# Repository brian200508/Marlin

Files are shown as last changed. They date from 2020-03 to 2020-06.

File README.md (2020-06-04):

Brian Schroeder's RepRap FTI-Strap
==================================
Another Fischertechnik RepRap Strap (using Marlin 3D Printer Firmware) built with Fischertechnik parts of the late 80's and some non-Fischertechnik pars from today; especially
- Nema 17 Stepper Motors
- MK 8 Extruder
- Arduino AVR Mega ATMEGA256
- RAMPS 1.6 Board
- GT2 timing belts and gears

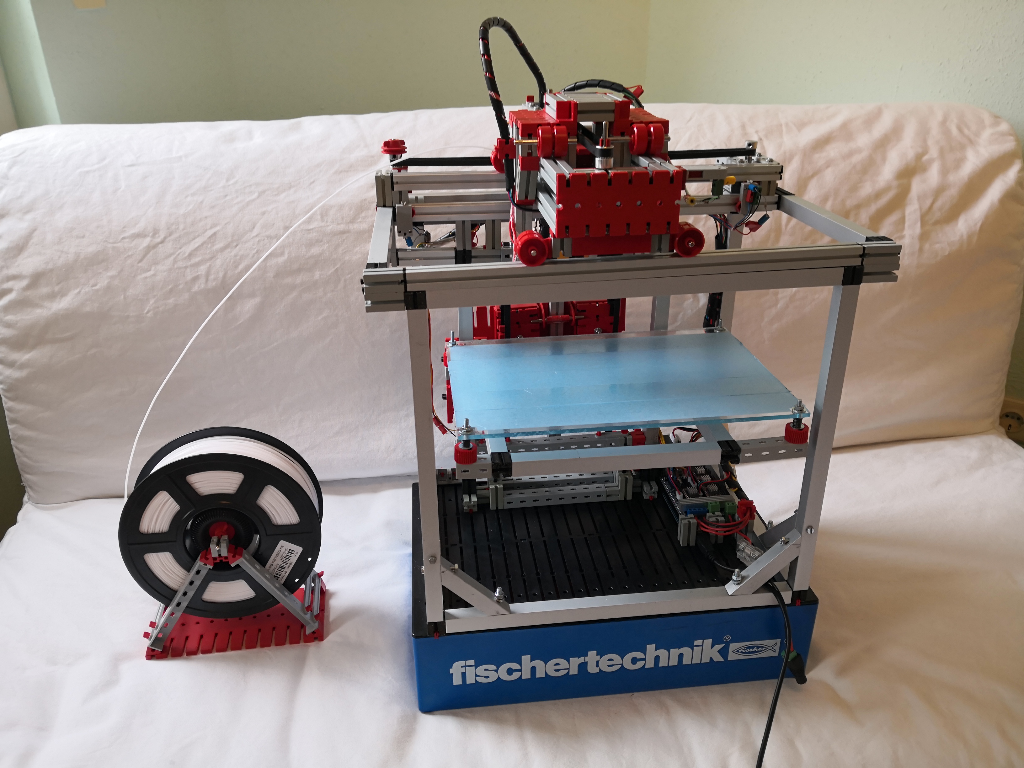
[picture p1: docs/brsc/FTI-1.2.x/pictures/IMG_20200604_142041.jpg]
Photo RepRap FTI-Strap


For more Details concerning the mechanics see ```docs/brsc/FTI-1.2.x```.

Thanks and very best Regards to Marlin and RepRap.
- https://github.com/MarlinFirmware/Marlin
- https://reprap.org

# Marlin 3D Printer Firmware








Additional documentation can be found at the [Marlin Home Page](http://marlinfw.org/).
Please let us know if Marlin misbehaves in any way. Volunteers are standing by!

## Marlin 2.0

Marlin 2.0 takes this popular RepRap firmware to the next level by adding support for much faster 32-bit and ARM-based boards while improving support for 8-bit AVR boards. Read about Marlin's decision to use a "Hardware Abstraction Layer" below.

Download earlier versions of Marlin on the [Releases page](https://github.com/MarlinFirmware/Marlin/releases).

## Building Marlin 2.0

To build Marlin 2.0 you'll need [Arduino IDE 1.8.8 or newer](https://www.arduino.cc/en/main/software) or [PlatformIO](http://docs.platformio.org/en/latest/ide.html#platformio-ide). Detailed build and install instructions are posted at:

  - [Installing Marlin (Arduino)](http://marlinfw.org/docs/basics/install_arduino.html)
  - [Installing Marlin (VSCode)](http://marlinfw.org/docs/basics/install_platformio_vscode.html).

### Supported Platforms

  Platform|MCU|Example Boards
  --------|---|-------
  [Arduino AVR](https://www.arduino.cc/)|ATmega|RAMPS, Melzi, RAMBo
  [Teensy++ 2.0](http://www.microchip.com/wwwproducts/en/AT90USB1286)|AT90USB1286|Printrboard
  [Arduino Due](https://www.arduino.cc/en/Guide/ArduinoDue)|SAM3X8E|RAMPS-FD, RADDS, RAMPS4DUE
  [LPC1768](http://www.nxp.com/products/microcontrollers-and-processors/arm-based-processors-and-mcus/lpc-cortex-m-mcus/lpc1700-cortex-m3/512kb-flash-64kb-sram-ethernet-usb-lqfp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)|ARM® Cortex-M3|MKS SBASE, Re-ARM, Selena Compact
  [LPC1769](https://www.nxp.com/products/processors-and-microcontrollers/arm-microcontrollers/general-purpose-mcus/lpc1700-cortex-m3/512kb-flash-64kb-sram-ethernet-usb-lqfp100-p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)|ARM® Cortex-M3|Smoothieboard, Azteeg X5 mini, TH3D EZBoard
  [STM32F103](https://www.st.com/en/microcontrollers-microprocessors/stm32f103.html)|ARM® Cortex-M3|Malyan M200, GTM32 Pro, MKS Robin, BTT SKR Mini
  [STM32F401](https://www.st.com/en/microcontrollers-microprocessors/stm32f401.html)|ARM® Cortex-M4|ARMED, Rumba32, SKR Pro, Lerdge, FYSETC S6
  [STM32F7x6](https://www.st.com/en/microcontrollers-microprocessors/stm32f7x6.html)|ARM® Cortex-M7|The Borg, RemRam V1
  [SAMD51P20A](https://www.adafruit.com/product/4064)|ARM® Cortex-M4|Adafruit Grand Central M4
  [Teensy 3.5](https://www.pjrc.com/store/teensy35.html)|ARM® Cortex-M4|
  [Teensy 3.6](https://www.pjrc.com/store/teensy36.html)|ARM® Cortex-M4|

## Submitting Changes

- Submit **Bug Fixes** as Pull Requests to the ([bugfix-2.0.x](https://github.com/MarlinFirmware/Marlin/tree/bugfix-2.0.x)) branch.
- Submit **New Features** to the ([dev-2.1.x](https://github.com/MarlinFirmware/Marlin/tree/dev-2.1.x)) branch.
- Follow the [Coding Standards](http://marlinfw.org/docs/development/coding_standards.html) to gain points with the maintainers.
- Please submit your questions and concerns to the [Issue Queue](https://github.com/MarlinFirmware/Marlin/issues).

## Marlin Support

For best results getting help with configuration and troubleshooting, please use the following resources:

- [Marlin Documentation](http://marlinfw.org) - Official Marlin documentation
- [Marlin Discord](https://discord.gg/n5NJ59y) - Discuss issues with Marlin users and developers
- Facebook Group ["Marlin Firmware"](https://www.facebook.com/groups/1049718498464482/)
- RepRap.org [Marlin Forum](http://forums.reprap.org/list.php?415)
- [Tom's 3D Forums](https://discuss.toms3d.org/)
- Facebook Group ["Marlin Firmware for 3D Printers"](https://www.facebook.com/groups/3Dtechtalk/)
- [Marlin Configuration](https://www.youtube.com/results?search_query=marlin+configuration) on YouTube

## Credits

The current Marlin dev team consists of:

 - Scott Lahteine [[@thinkyhead](https://github.com/thinkyhead)] - USA &nbsp; [Donate](http://www.thinkyhead.com/donate-to-marlin) / Flattr: 
 - Roxanne Neufeld [[@Roxy-3D](https://github.com/Roxy-3D)] - USA
 - Chris Pepper [[@p3p](https://github.com/p3p)] - UK
 - Bob Kuhn [[@Bob-the-Kuhn](https://github.com/Bob-the-Kuhn)] - USA
 - João Brazio [[@jbrazio](https://github.com/jbrazio)] - Portugal
 - Erik van der Zalm [[@ErikZalm](https://github.com/ErikZalm)] - Netherlands &nbsp; 

## License

Marlin is published under the [GPL license](/LICENSE) because we believe in open development. The GPL comes with both rights and obligations. Whether you use Marlin firmware as the driver for your open or closed-source product, you must keep Marlin open, and you must provide your compatible Marlin source code to end users upon request. The most straightforward way to comply with the Marlin license is to make a fork of Marlin on Github, perform your modifications, and direct users to your modified fork.

While we can't prevent the use of this code in products (3D printers, CNC, etc.) that are closed source or crippled by a patent, we would prefer that you choose another firmware or, better yet, make your own.

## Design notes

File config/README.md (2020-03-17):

# Where have all the configurations gone?

## https://github.com/MarlinFirmware/Configurations/archive/release-2.0.5.zip

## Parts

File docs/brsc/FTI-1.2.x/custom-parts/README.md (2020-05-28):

Brian Schroeder's RepRap FTI-Strap
==================================

Custom parts required for brsc/FTI-1.2.1.

# Chassis

          O. o . . . . . . . . . . . .oO
         /. .|. . . . . . . . . . . . /
        f    b  o          o         f|
       /     |  g          g        / b
      o............................o  |
      ..+----------- a ----------+.. :|
        |  e:+ .g.         g     |  e:+
        b  :/   O. . . . . O     b  :/
        |__/ _ e                 |__/ _ e
        |\c                     /| c
        |/\ d                d / |/
        L----------- a ----------R

## Self printed parts
- o) 6x 'aluminum-square-tube-15x15-to-Fischertechnik-adapter-15' aluminum-square-tube-15x15-to-Fischertechnik-adapter-15
- O) 4x 'aluminum-square-tube-15x15-to-Fischertechnik-adapter-45' aluminum-square-tube-15x15-to-Fischertechnik-adapter-45
- L) 1 part of 'aluminum-square-tube-15x15-to-Fischertechnik-adapter-x-y-z-15-L' aluminum-square-tube-15x15-to-Fischertechnik-adapter-x-y-z-15-L
- R) 1 part of 'aluminum-square-tube-15x15-to-Fischertechnik-adapter-x-y-z-15-R' aluminum-square-tube-15x15-to-Fischertechnik-adapter-x-y-z-15-R
- +) 4x 'aluminum-square-tube-15x15-to-Fischertechnik-adapter-y-z-15' aluminum-square-tube-15x15-to-Fischertechnik-adapter-y-z-15

## Standard (non-Fischertechnik parts)
- a) 2x aluminium square tube 15mm x 15mm, length=330mm
- b) 4x aluminium square tube 15mm x 15mm, length=300mm
- c) 2x aluminium square tube 15mm x 15mm, length=210mm
- d) 2x aluminium square tube 15mm x 15mm, length=85mm
- e) 4x aluminium square tube 15mm x 15mm, length=105mm
- f) 2x aluminium square tube 15mm x 15mm, length=180mm
- g) 2x aluminium square tube 15mm x 15mm, length=240mm
- 8x Screw M4, etc.
- 8x Screw M5, etc.

# Bed

Chassis only

                . . . . . . . . . . .
                :...o----- d -----o.:
                :  :               ::
                H+==------ e ------=:+
              . O. . . .  ... . . . O. . ..
               O:         .        O:
              Oo--- a --~~~~- b -oO : 
             / \: . . . .\. . . ./.\.
            c                   c
         . L-------- f --------L. . ..

Chassis with Plexiglass board (P) and angles (*)

                . . . . . . . . . . .
                :...o----- d -----o.:
              PPPPPPPPPPPPPPPPPPPPPPPPPPPPP
             PS H+==------ e ------=:+   PS
            P . O. . . .  ... . . . O. .P..
           P   O:         .        O:  P
          P   Oo--- a --~~~~- b -oO : P
         PPPPPPPPPPPPPPPPPPPPPPPPPPPPP
         S  c                   c    S
         . L-------- f --------L. . ..

## Self printed parts
- +) 2x 'aluminum-square-tube-15x15-to-Fischertechnik-adapter-x-y-30-X-X'; one shortened at junction ```o_+``` aluminum-square-tube-15x15-to-Fischertechnik-adapter-x-y-30-X-X
- o) 4x 'aluminum-square-tube-15x15-to-Fischertechnik-adapter-15' aluminum-square-tube-15x15-to-Fischertechnik-adapter-15
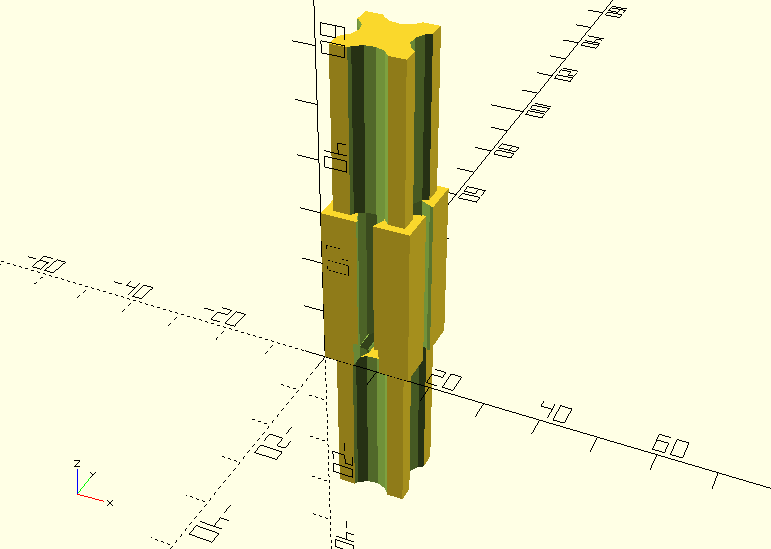
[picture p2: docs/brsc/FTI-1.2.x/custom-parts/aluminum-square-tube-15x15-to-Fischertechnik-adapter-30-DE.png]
aluminum-square-tube-15x15-to-Fischertechnik-adapter-30-DE
- ~) 1x 'aluminum-square-tube-15x15-to-Fischertechnik-adapter-30-DE' 
- O) 2x 'aluminum-square-tube-15x15-to-Fischertechnik-adapter-75' aluminum-square-tube-15x15-to-Fischertechnik-adapter-75
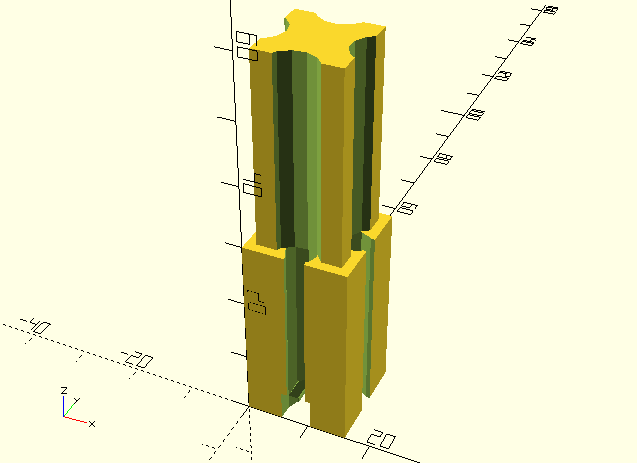
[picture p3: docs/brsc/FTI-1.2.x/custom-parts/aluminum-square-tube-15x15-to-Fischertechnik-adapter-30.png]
aluminum-square-tube-15x15-to-Fischertechnik-adapter-30
- =) 2x 'aluminum-square-tube-15x15-to-Fischertechnik-adapter-30' 
- L) 2x 'aluminum-square-tube-15x15-to-Fischertechnik-adapter-y-z-15' aluminum-square-tube-15x15-to-Fischertechnik-adapter-y-z-15

## Standard (non-Fischertechnik parts)
- a) 1x aluminium square tube 15mm x 15mm, length=75mm
- b) 1x aluminium square tube 15mm x 15mm, length=45mm
- c) 2x aluminium square tube 15mm x 15mm, length=120mm
- d) 1x aluminium square tube 15mm x 15mm, length=75mm
- e) 1x aluminium square tube 15mm x 15mm, length=105mm
- f) 1x aluminium square tube 15mm x 15mm, length=180mm
- S) 8x Screw M4, etc.
- P) 1x Plexiglass board 300mm x 210mm, d=5mm

Details see photos.

# Mechanics and Gears

## Thingiverse
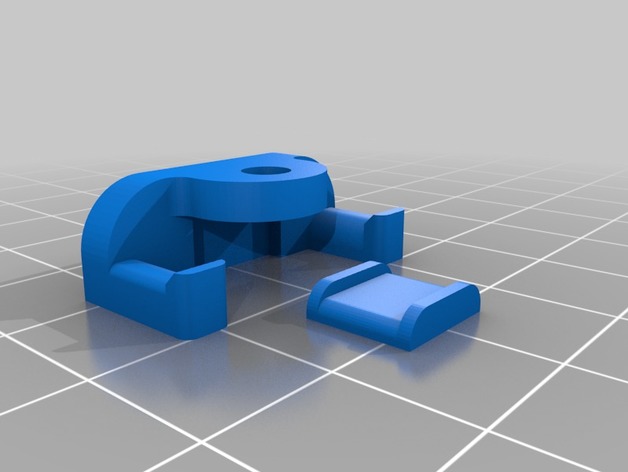
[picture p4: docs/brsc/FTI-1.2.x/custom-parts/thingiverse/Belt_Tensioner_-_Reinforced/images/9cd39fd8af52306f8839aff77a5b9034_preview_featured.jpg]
Belt_Tensioner_-_Reinforced
- 2x 'Belt_Tensioner_-_Reinforced'

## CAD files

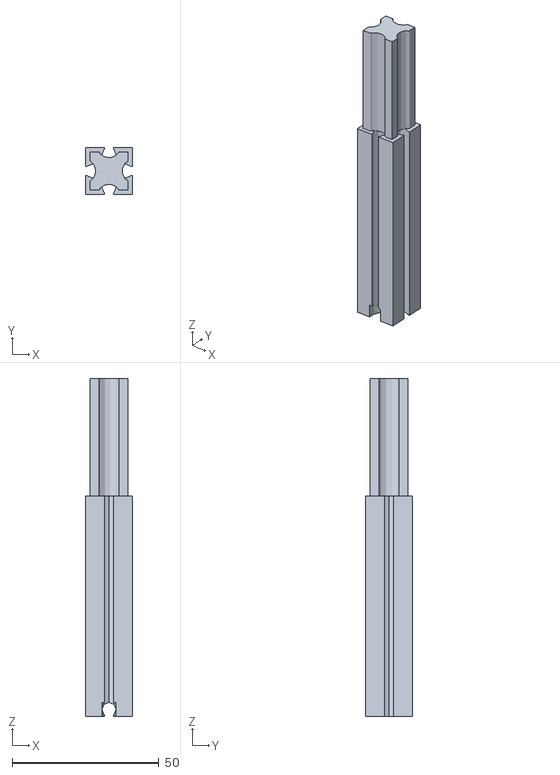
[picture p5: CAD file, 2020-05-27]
docs/brsc/FTI-1.2.x/custom-parts/aluminum-square-tube-15x15-to-Fischertechnik-adapter-75.stl
16.0 x 16.0 x 115.0

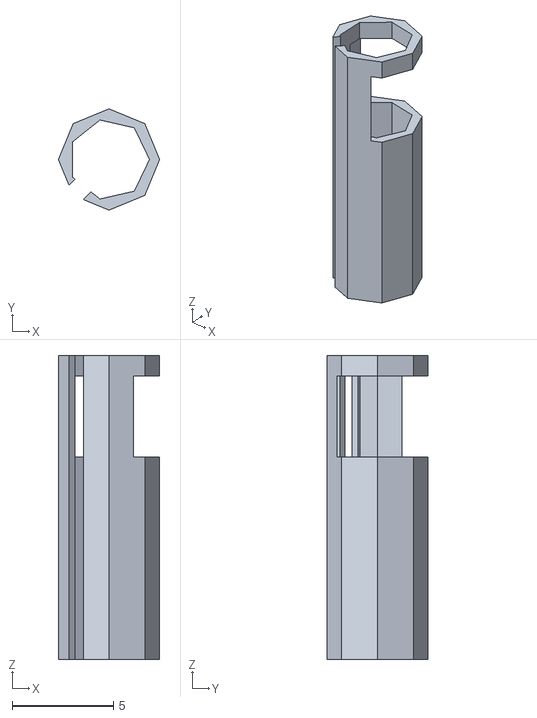
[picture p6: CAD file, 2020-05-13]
docs/brsc/FTI-1.2.x/custom-parts/not-used/axis-5mm-to-4mm-Fischertechnik-adapter.stl
5.00 x 5.00 x 15.0

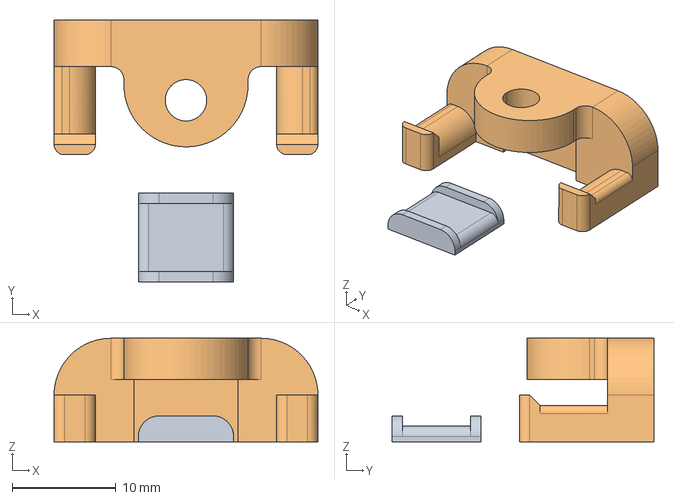
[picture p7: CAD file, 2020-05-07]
docs/brsc/FTI-1.2.x/custom-parts/thingiverse/Belt_Tensioner_-_Reinforced/files/Belt_Tensioner_-_Thicker.stp
25.5 x 25.3 x 10.0 mm

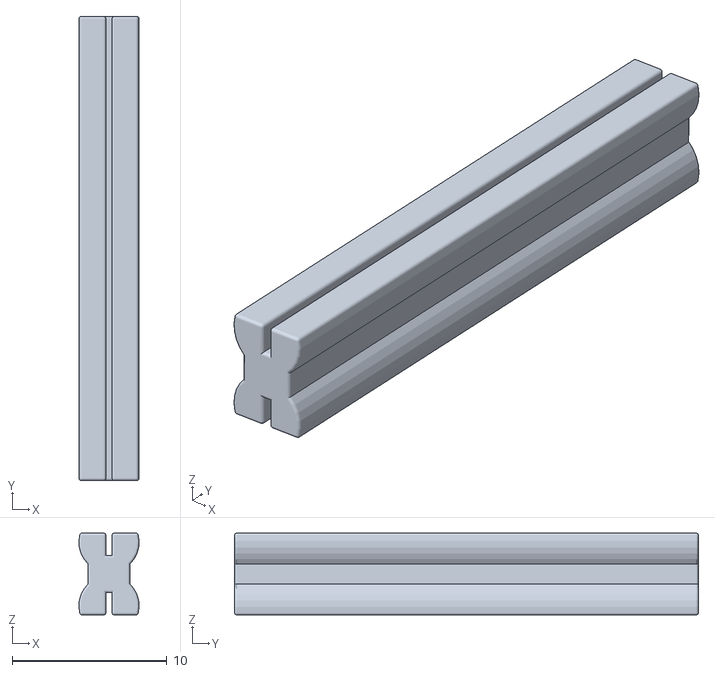
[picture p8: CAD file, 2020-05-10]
docs/brsc/FTI-1.2.x/custom-parts/thingiverse/fischertechnik_double_flat_connector/files/Connector_30mm_v1.stl
3.90 x 30.0 x 5.30

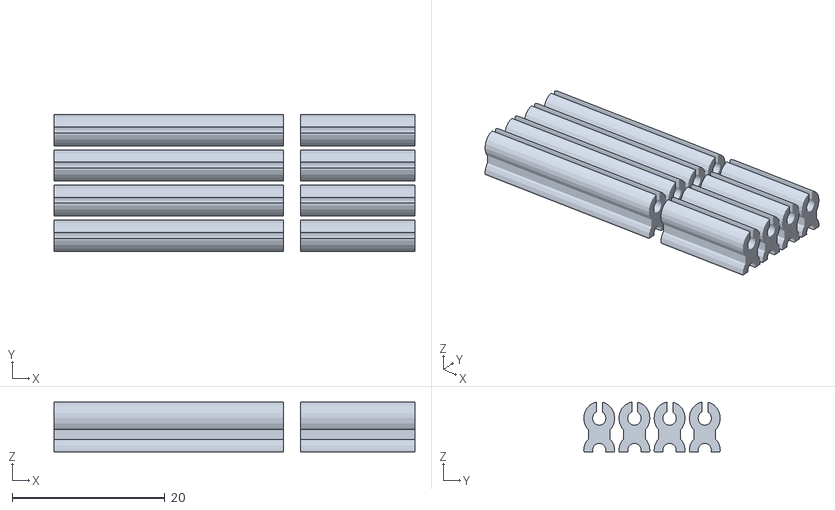
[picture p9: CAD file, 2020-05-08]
docs/brsc/FTI-1.2.x/custom-parts/thingiverse/Fischertechnik_Double_GroovePin_SmartLab/files/fischertechnik_double_groovepin_smartlab.stl
47.2 x 17.9 x 6.50

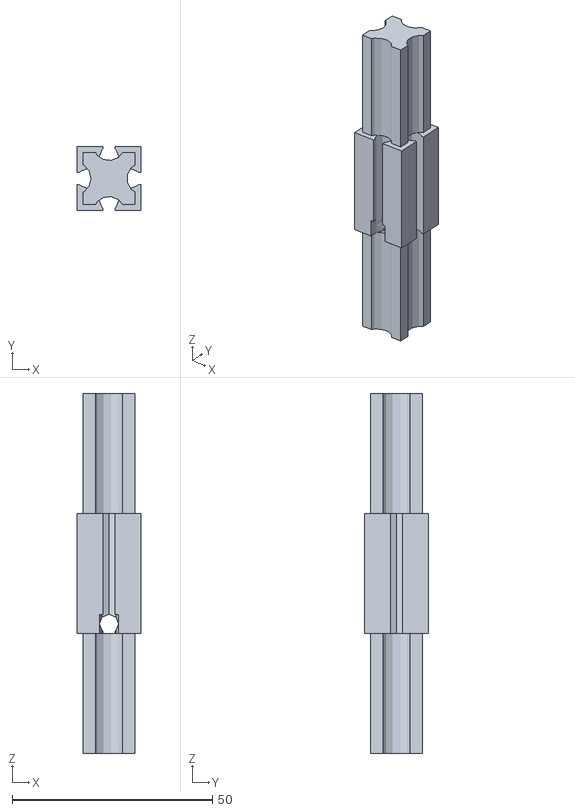
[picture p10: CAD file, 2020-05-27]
docs/brsc/FTI-1.2.x/custom-parts/aluminum-square-tube-15x15-to-Fischertechnik-adapter-30-DE.stl
16.0 x 16.0 x 90.0

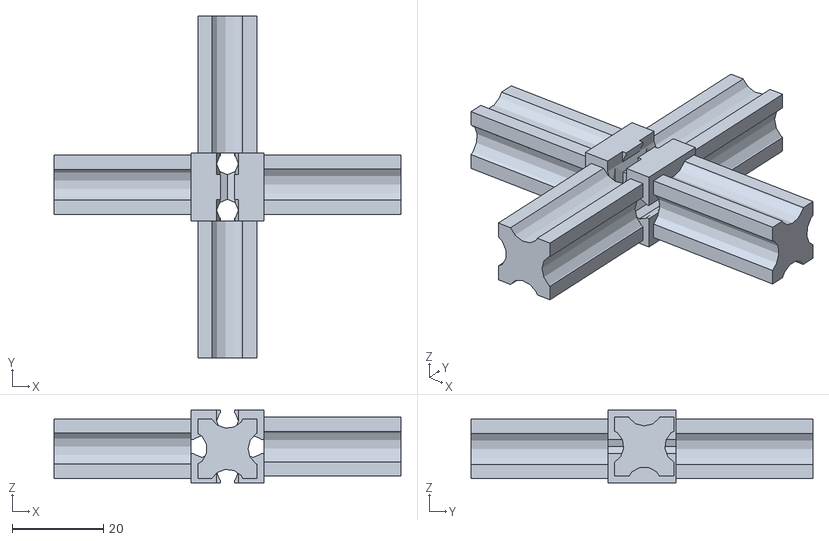
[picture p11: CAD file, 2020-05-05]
docs/brsc/FTI-1.2.x/custom-parts/not-used/aluminum-square-tube-15x15-to-Fischertechnik-adapter-x-y-15-X-Z.stl
76.0 x 75.0 x 16.0

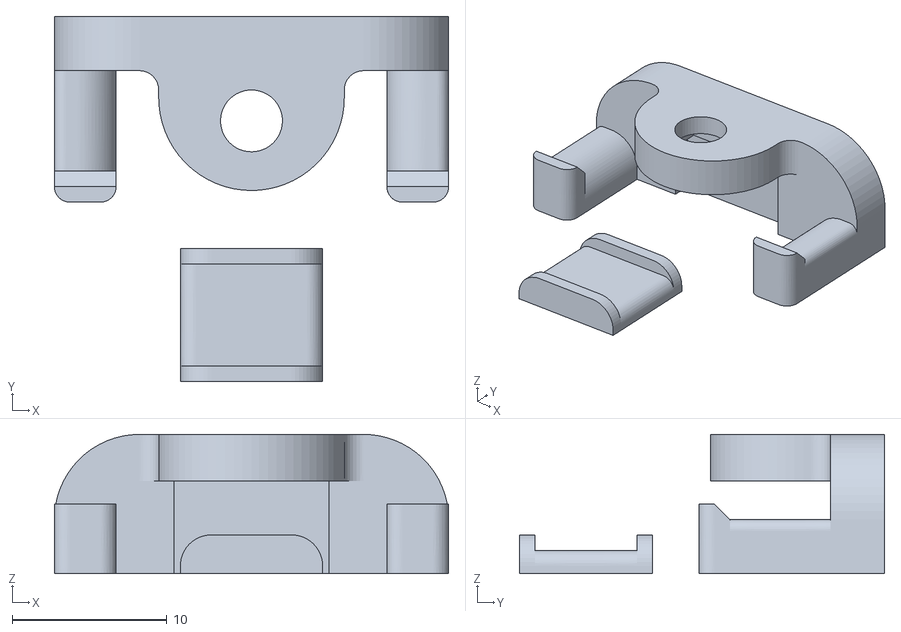
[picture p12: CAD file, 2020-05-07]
docs/brsc/FTI-1.2.x/custom-parts/thingiverse/Belt_Tensioner_-_Reinforced/files/Belt_Tensioner.stl
25.5 x 23.6 x 9.00

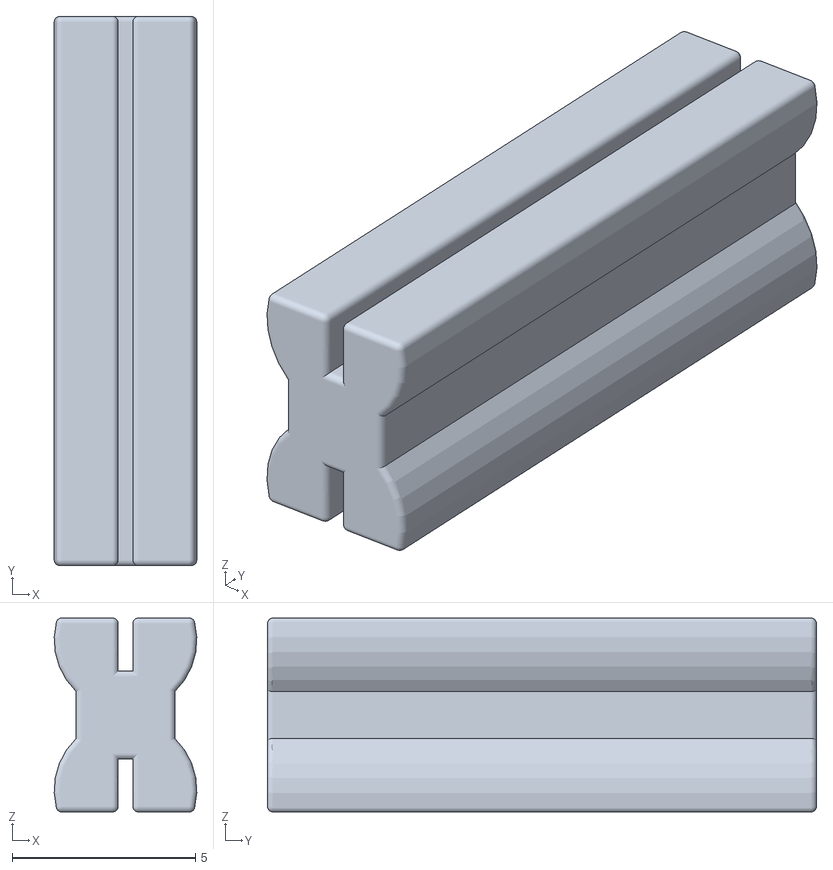
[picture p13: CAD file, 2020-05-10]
docs/brsc/FTI-1.2.x/custom-parts/thingiverse/fischertechnik_double_flat_connector/files/Connector_15mm_v1.stl
3.90 x 15.0 x 5.30

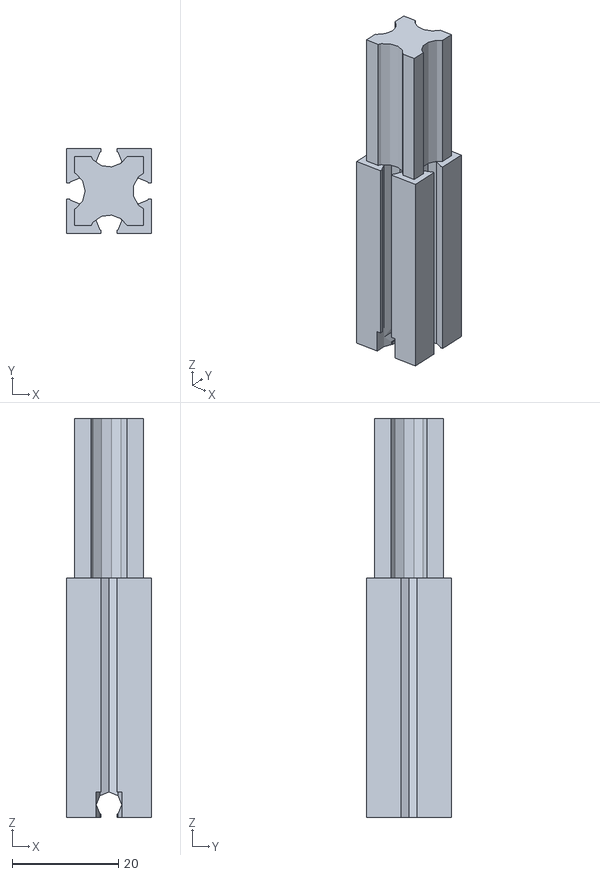
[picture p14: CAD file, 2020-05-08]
docs/brsc/FTI-1.2.x/custom-parts/aluminum-square-tube-15x15-to-Fischertechnik-adapter-45.stl
16.0 x 16.0 x 75.0

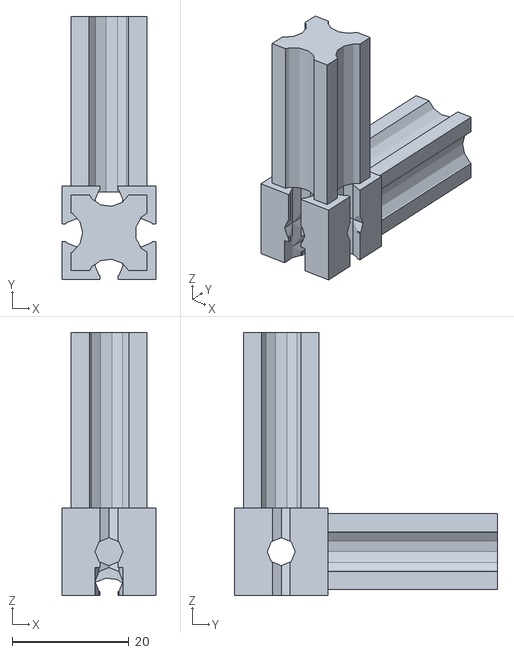
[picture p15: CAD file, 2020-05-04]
docs/brsc/FTI-1.2.x/custom-parts/not-used/aluminum-square-tube-15x15-to-Fischertechnik-adapter-y-z-15-with-hole.stl
16.0 x 45.0 x 45.0

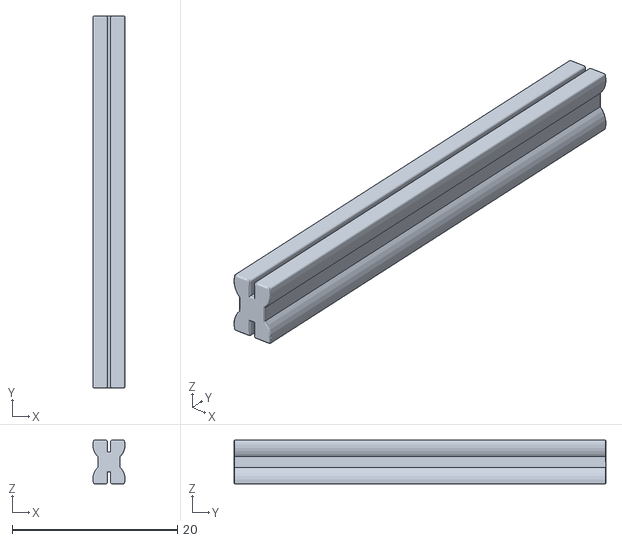
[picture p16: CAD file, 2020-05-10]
docs/brsc/FTI-1.2.x/custom-parts/thingiverse/fischertechnik_double_flat_connector/files/Connector_45mm_v1.stl
3.90 x 45.0 x 5.30

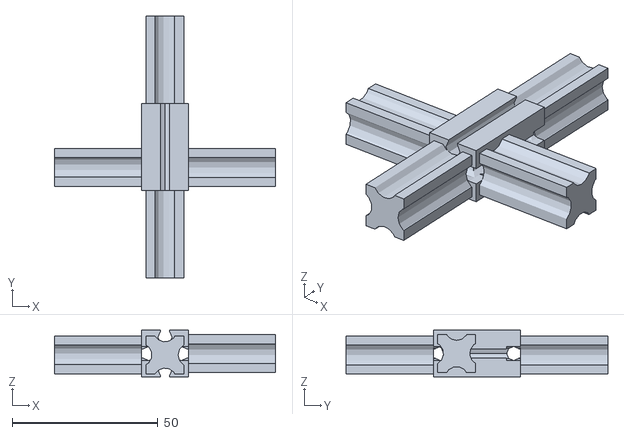
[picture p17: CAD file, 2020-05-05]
docs/brsc/FTI-1.2.x/custom-parts/aluminum-square-tube-15x15-to-Fischertechnik-adapter-x-y-30-X-X.stl
76.0 x 90.0 x 16.0

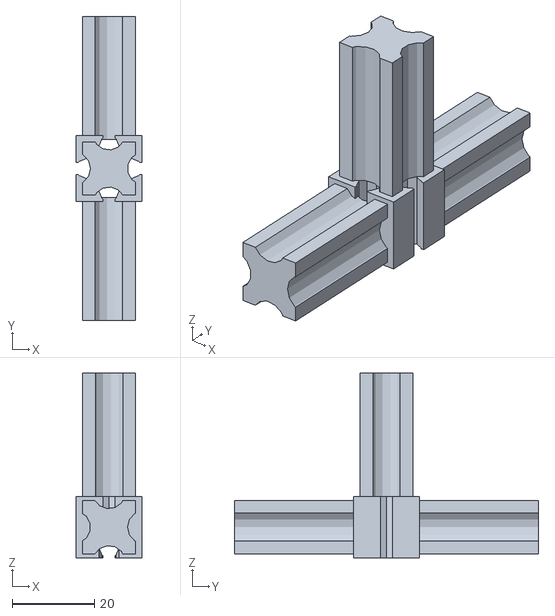
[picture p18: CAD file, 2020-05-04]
docs/brsc/FTI-1.2.x/custom-parts/not-used/aluminum-square-tube-15x15-to-Fischertechnik-adapter-y-z-15-T.stl
16.0 x 74.0 x 45.0

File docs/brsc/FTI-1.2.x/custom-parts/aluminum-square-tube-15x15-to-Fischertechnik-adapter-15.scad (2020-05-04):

/**
 * Create an adapter for connecting a 15x15 square tube to Fischertechnik.
 *
 * @author Brian Schroeder
 * @since 21.04.2020
 */

/* [End Cap length] */
// Fischertechnik compatible end cap length in millimeters
EndCapLength=15; // [15, 30, 45, 60, 75, 90]

/*
 * Create the adapter with Fischertechnik compatible end cap length passed by the argument.
 *
 * @param ftiEndCapLength end cap length in millimeters (default is 15)
 */
module ftiSpuareTubeAdapter15x15(ftiEndCapLength=15) {

    union() {
        dBlock=15 + 1; // block (max) diameter + some more around (adjust to Your printer)
        hTubeConn=(ftiEndCapLength < 60) ? 30 : (ftiEndCapLength < 75 ? 45 : 60);
        dCarveOut=8; // carve out diameter
        oCarveOut=6; // carve out offset
        dConnector=12.5 + .5; // connector (max) diameter + some more around (adjust to Your printer)
        dBorder=(dBlock-dConnector)/2; // the square tube border diameter

        // Fischertechnik connector part
        difference() {
            dFti=4 + .8; // axis diameter 4mm + some space around
            gFtiW=3; // with of gap
            gFtiD=2; // depth of gap
            cube([dBlock, dBlock, ftiEndCapLength]);
            // axis
            translate([dBlock/2,dFti/2,0])cylinder(h=ftiEndCapLength, d=dFti);
            translate([dBlock/2,dBlock-dFti/2,0])cylinder(h=ftiEndCapLength, d=dFti);
            translate([dBlock-dFti/2,dBlock/2,0])cylinder(h=ftiEndCapLength, d=dFti);
            translate([dFti/2,dBlock/2,0])cylinder(h=ftiEndCapLength, d=dFti);
            // space
            translate([dBlock/2-gFtiW/2,0,0])cube([gFtiW, gFtiD, ftiEndCapLength]);
            translate([dBlock/2-gFtiW/2,dBlock-gFtiD,0])cube([gFtiW, gFtiD, ftiEndCapLength]);
            translate([dBlock-gFtiW/2,dBlock/2-gFtiW/2,0])cube([gFtiD, gFtiW, ftiEndCapLength]);
            translate([0,dBlock/2-gFtiW/2,0])cube([gFtiD, gFtiW, ftiEndCapLength]);
            // orthoganal axis at end
            translate([dBlock/2, dBlock, dFti/2])rotate([90, 0, 0])cylinder(h=dBlock, d=dFti);
            translate([dBlock/2-dFti/2, dBlock-dFti/2, 0])cube([dFti, dFti, dFti]);
            translate([dBlock/2-dFti/2, 0-dFti/2, 0])cube([dFti, dFti, dFti]);
            translate([dBlock/2+gFtiW/2, 0, -gFtiD/2])rotate([270, 180, 0])cube([gFtiW, gFtiD, dBlock]);
        }

        // square tube connector part
        translate([dBorder, dBorder, ftiEndCapLength])difference() {
            // corpus
            cube([dConnector, dConnector, hTubeConn]);
            // space
            translate([dConnector/2,dCarveOut/2-oCarveOut,0])cylinder(h=hTubeConn, d=dCarveOut);
            translate([dConnector/2,dConnector-dCarveOut/2+oCarveOut,0])cylinder(h=hTubeConn, d=dCarveOut);
            translate([dConnector-dCarveOut/2+oCarveOut,dConnector/2,0])cylinder(h=hTubeConn, d=dCarveOut);
            translate([dCarveOut/2-oCarveOut,dConnector/2,0])cylinder(h=hTubeConn, d=dCarveOut);
        }
    }
}

ftiSpuareTubeAdapter15x15(EndCapLength);

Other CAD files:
docs/brsc/FTI-1.2.x/custom-parts/aluminum-square-tube-15x15-to-Fischertechnik-adapter-15.stl
docs/brsc/FTI-1.2.x/custom-parts/not-used/aluminum-square-tube-15x15-to-Fischertechnik-adapter-30.stl
docs/brsc/FTI-1.2.x/custom-parts/aluminum-square-tube-15x15-to-Fischertechnik-adapter-x-y-z-15-R.stl
docs/brsc/FTI-1.2.x/custom-parts/not-used/Fischertechnik-compatible-building-block-with-hole-90.stl
docs/brsc/FTI-1.2.x/custom-parts/aluminum-square-tube-15x15-to-Fischertechnik-adapter-30-DE.scad
docs/brsc/FTI-1.2.x/custom-parts/aluminum-square-tube-15x15-to-Fischertechnik-adapter-30.scad
docs/brsc/FTI-1.2.x/custom-parts/aluminum-square-tube-15x15-to-Fischertechnik-adapter-45.scad
docs/brsc/FTI-1.2.x/custom-parts/aluminum-square-tube-15x15-to-Fischertechnik-adapter-30.stl
docs/brsc/FTI-1.2.x/custom-parts/aluminum-square-tube-15x15-to-Fischertechnik-adapter-75.scad
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

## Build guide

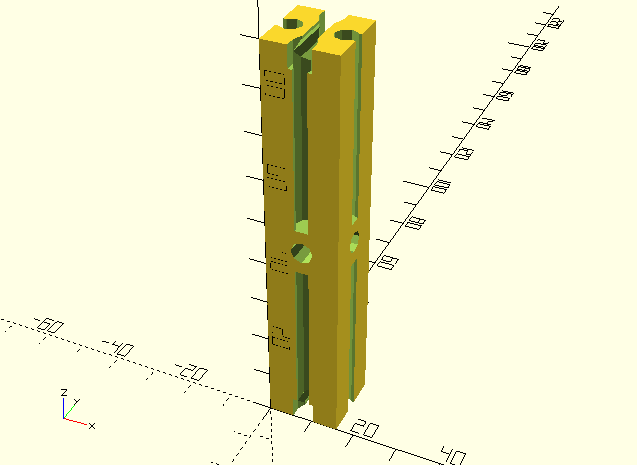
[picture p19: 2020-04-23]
docs/brsc/FTI-1.2.x/custom-parts/not-used/Fischertechnik-compatible-building-block-with-hole-90.png

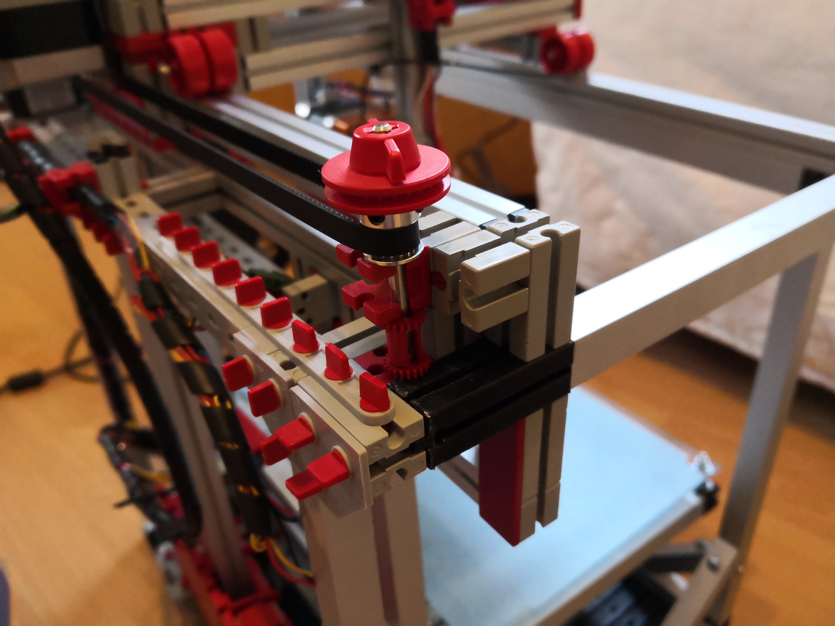
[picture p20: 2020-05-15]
docs/brsc/FTI-1.2.x/pictures/intermediate-step-6-FTI-1.2.1/IMG_20200514_191627.jpg

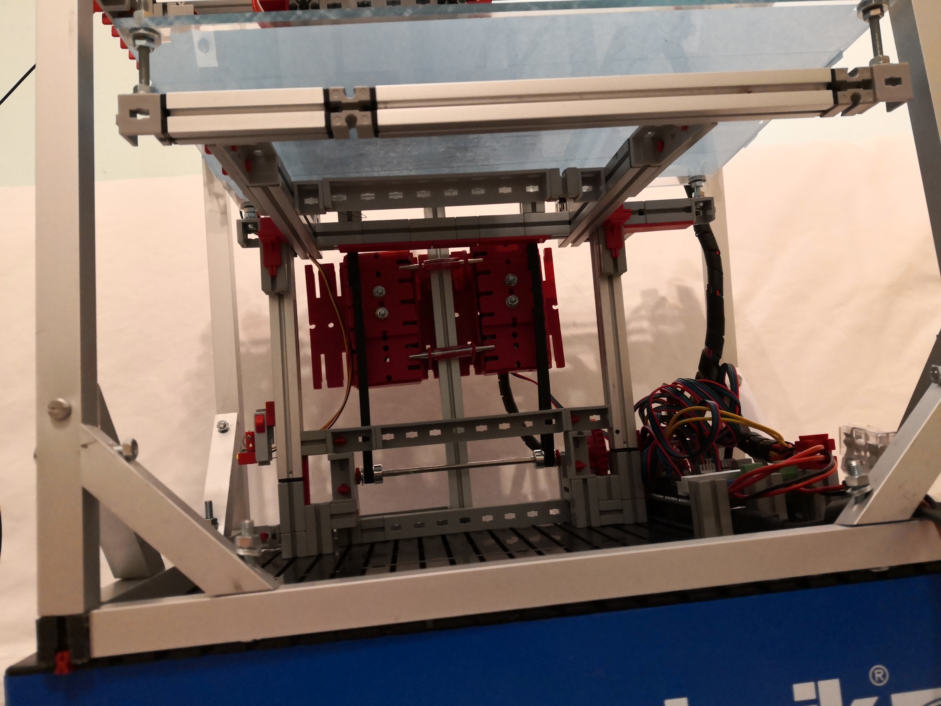
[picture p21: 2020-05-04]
docs/brsc/FTI-1.2.x/pictures/intermediate-step-1/IMG_20200503_230225.jpg

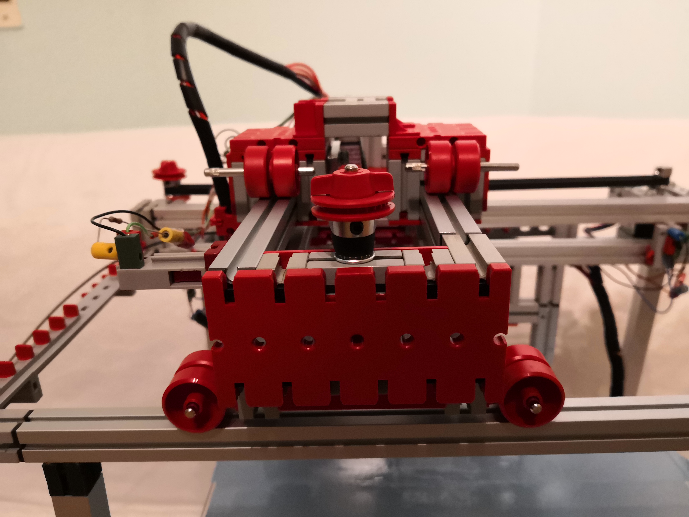
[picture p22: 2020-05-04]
docs/brsc/FTI-1.2.x/pictures/intermediate-step-1/IMG_20200503_230522.jpg

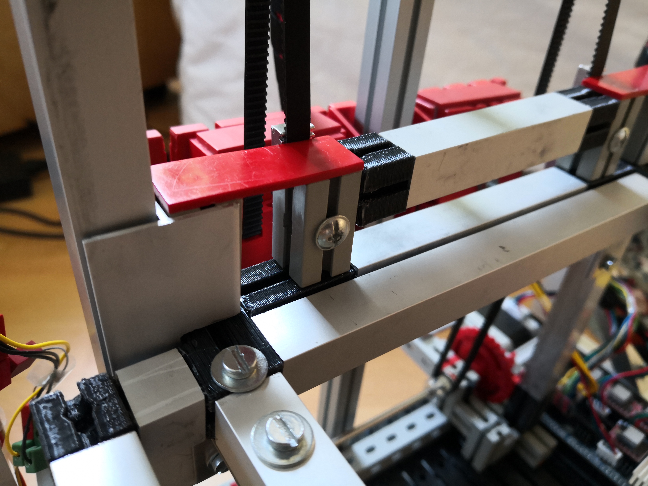
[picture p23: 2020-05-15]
docs/brsc/FTI-1.2.x/pictures/intermediate-step-6-FTI-1.2.1/IMG_20200514_114916.jpg

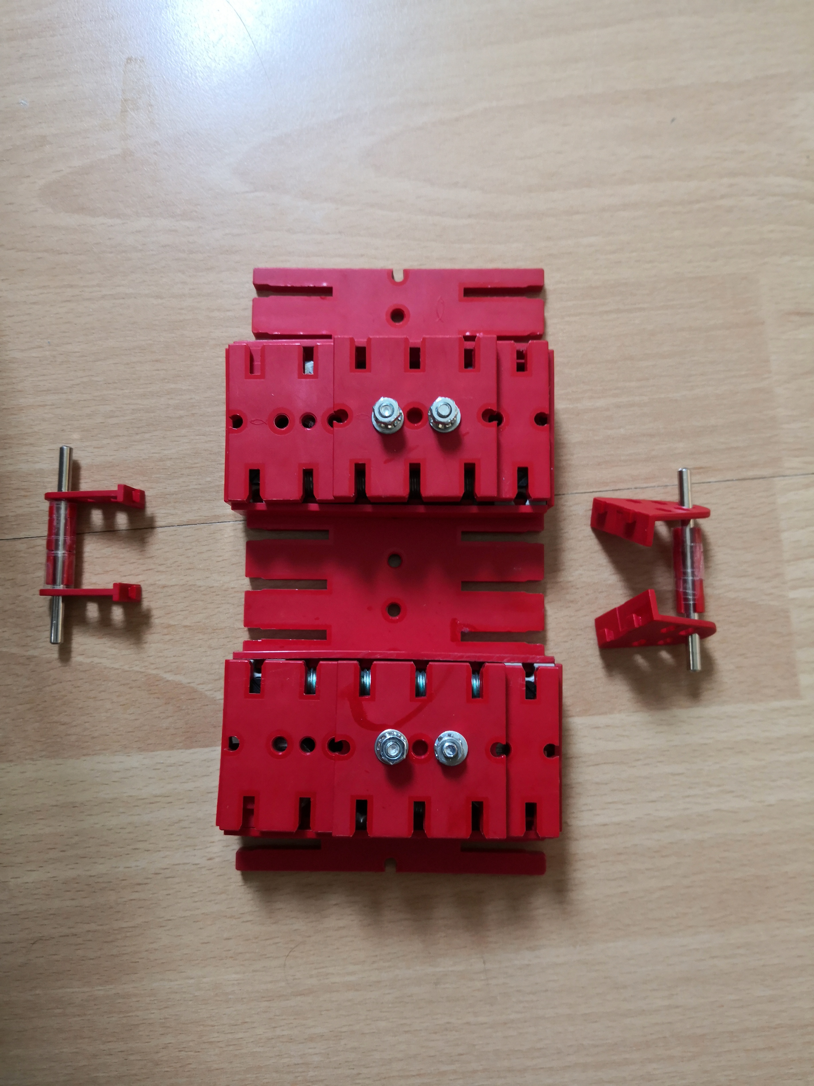
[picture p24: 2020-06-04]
docs/brsc/FTI-1.2.x/pictures/intermediate-step-7/IMG_20200604_112008.jpg

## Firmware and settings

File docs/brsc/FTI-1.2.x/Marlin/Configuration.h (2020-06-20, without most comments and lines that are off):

#pragma once
#define CONFIGURATION_H_VERSION 020005
#define STRING_CONFIG_H_AUTHOR "(none, default config)" // Who made the changes.
#define SHOW_BOOTSCREEN
#define SERIAL_PORT 0
#define BAUDRATE 250000
  #define MOTHERBOARD BOARD_RAMPS_14_EFB
#define EXTRUDERS 1
#define DEFAULT_NOMINAL_FILAMENT_DIA 1.75
#define TEMP_SENSOR_0 1
#define TEMP_SENSOR_1 0
#define TEMP_SENSOR_2 0
#define TEMP_SENSOR_3 0
#define TEMP_SENSOR_4 0
#define TEMP_SENSOR_5 0
#define TEMP_SENSOR_6 0
#define TEMP_SENSOR_7 0
#define TEMP_SENSOR_BED 0
#define TEMP_SENSOR_PROBE 0
#define TEMP_SENSOR_CHAMBER 0
#define DUMMY_THERMISTOR_998_VALUE 25
#define DUMMY_THERMISTOR_999_VALUE 100
#define MAX_REDUNDANT_TEMP_SENSOR_DIFF 10
#define TEMP_RESIDENCY_TIME     10  // (seconds) Time to wait for hotend to "settle" in M109
#define TEMP_WINDOW              1  // (°C) Temperature proximity for the "temperature reached" timer
#define TEMP_HYSTERESIS          3  // (°C) Temperature proximity considered "close enough" to the target
#define TEMP_BED_RESIDENCY_TIME 10  // (seconds) Time to wait for bed to "settle" in M190
#define TEMP_BED_WINDOW          1  // (°C) Temperature proximity for the "temperature reached" timer
#define TEMP_BED_HYSTERESIS      3  // (°C) Temperature proximity considered "close enough" to the target
#define HEATER_0_MINTEMP   5
#define HEATER_1_MINTEMP   5
#define HEATER_2_MINTEMP   5
#define HEATER_3_MINTEMP   5
#define HEATER_4_MINTEMP   5
#define HEATER_5_MINTEMP   5
#define HEATER_6_MINTEMP   5
#define HEATER_7_MINTEMP   5
#define BED_MINTEMP        5
#define HEATER_0_MAXTEMP 230
#define HEATER_1_MAXTEMP 230
#define HEATER_2_MAXTEMP 230
#define HEATER_3_MAXTEMP 230
#define HEATER_4_MAXTEMP 230
#define HEATER_5_MAXTEMP 230
#define HEATER_6_MAXTEMP 230
#define HEATER_7_MAXTEMP 230
#define BED_MAXTEMP      150
#define PIDTEMP
#define BANG_MAX 255     // Limits current to nozzle while in bang-bang mode; 255=full current
#define PID_MAX BANG_MAX // Limits current to nozzle while PID is active (see PID_FUNCTIONAL_RANGE below); 255=full current
#define PID_K1 0.95      // Smoothing factor within any PID loop
  #define PID_FUNCTIONAL_RANGE 10 // If the temperature difference between the target temperature and the actual temperature
  #define DEFAULT_Kp 22.2
  #define DEFAULT_Ki 1.08
  #define DEFAULT_Kd 114
#define MAX_BED_POWER 255 // limits duty cycle to bed; 255=full current
#define PREVENT_COLD_EXTRUSION
#define EXTRUDE_MINTEMP 170
#define PREVENT_LENGTHY_EXTRUDE
#define EXTRUDE_MAXLENGTH 200
#define THERMAL_PROTECTION_HOTENDS // Enable thermal protection for all extruders
#define THERMAL_PROTECTION_BED     // Enable thermal protection for the heated bed
#define THERMAL_PROTECTION_CHAMBER // Enable thermal protection for the heated chamber
#define USE_XMIN_PLUG
#define USE_YMIN_PLUG
#define USE_ZMIN_PLUG
#define USE_XMAX_PLUG
#define USE_YMAX_PLUG
#define USE_ZMAX_PLUG
#define ENDSTOPPULLUPS
#define X_MIN_ENDSTOP_INVERTING false // Set to true to invert the logic of the endstop.
#define Y_MIN_ENDSTOP_INVERTING false // Set to true to invert the logic of the endstop.
#define Z_MIN_ENDSTOP_INVERTING false // Set to true to invert the logic of the endstop.
#define X_MAX_ENDSTOP_INVERTING false // Set to true to invert the logic of the endstop.
#define Y_MAX_ENDSTOP_INVERTING false // Set to true to invert the logic of the endstop.
#define Z_MAX_ENDSTOP_INVERTING false // Set to true to invert the logic of the endstop.
#define Z_MIN_PROBE_ENDSTOP_INVERTING false // Set to true to invert the logic of the probe.
#define DEFAULT_AXIS_STEPS_PER_UNIT   { 100, 100, 296, 93 }
#define DEFAULT_MAX_FEEDRATE          { 100, 100, 5, 25 }
#define DEFAULT_MAX_ACCELERATION      { 100, 100, 100, 1000 }
#define DEFAULT_ACCELERATION          100    // X, Y, Z and E acceleration for printing moves
#define DEFAULT_RETRACT_ACCELERATION  100    // E acceleration for retracts
#define DEFAULT_TRAVEL_ACCELERATION   100    // X, Y, Z acceleration for travel (non printing) moves
#define DEFAULT_EJERK    5.0  // May be used by Linear Advance
  #define JUNCTION_DEVIATION_MM 0.013 // (mm) Distance from real junction edge
#define Z_MIN_PROBE_USES_Z_MIN_ENDSTOP_PIN
#define NOZZLE_TO_PROBE_OFFSET { 10, 10, 0 }
#define MIN_PROBE_EDGE 10
#define XY_PROBE_SPEED 8000
#define Z_PROBE_SPEED_FAST HOMING_FEEDRATE_Z
#define Z_PROBE_SPEED_SLOW (Z_PROBE_SPEED_FAST / 2)
#define Z_CLEARANCE_DEPLOY_PROBE   10 // Z Clearance for Deploy/Stow
#define Z_CLEARANCE_BETWEEN_PROBES  5 // Z Clearance between probe points
#define Z_CLEARANCE_MULTI_PROBE     5 // Z Clearance between multiple probes
#define Z_PROBE_LOW_POINT          -2 // Farthest distance below the trigger-point to go before stopping
#define Z_PROBE_OFFSET_RANGE_MIN -20
#define Z_PROBE_OFFSET_RANGE_MAX 20
#define X_ENABLE_ON 0
#define Y_ENABLE_ON 0
#define Z_ENABLE_ON 0
#define E_ENABLE_ON 0 // For all extruders
#define DISABLE_X false
#define DISABLE_Y false
#define DISABLE_Z false
#define DISABLE_E false             // For all extruders
#define DISABLE_INACTIVE_EXTRUDER   // Keep only the active extruder enabled
#define INVERT_X_DIR false
#define INVERT_Y_DIR true
#define INVERT_Z_DIR false
#define INVERT_E0_DIR false
#define INVERT_E1_DIR false
#define INVERT_E2_DIR false
#define INVERT_E3_DIR false
#define INVERT_E4_DIR false
#define INVERT_E5_DIR false
#define INVERT_E6_DIR false
#define INVERT_E7_DIR false
#define X_HOME_DIR -1
#define Y_HOME_DIR -1
#define Z_HOME_DIR -1
#define X_BED_SIZE 230
#define Y_BED_SIZE 135
#define X_MIN_POS 0
#define Y_MIN_POS 0
#define Z_MIN_POS 0
#define X_MAX_POS X_BED_SIZE
#define Y_MAX_POS Y_BED_SIZE
#define Z_MAX_POS 105
#define MIN_SOFTWARE_ENDSTOPS
  #define MIN_SOFTWARE_ENDSTOP_X
  #define MIN_SOFTWARE_ENDSTOP_Y
  #define MIN_SOFTWARE_ENDSTOP_Z
#define MAX_SOFTWARE_ENDSTOPS
  #define MAX_SOFTWARE_ENDSTOP_X
  #define MAX_SOFTWARE_ENDSTOP_Y
  #define MAX_SOFTWARE_ENDSTOP_Z
#define HOMING_FEEDRATE_XY (50*60)
#define HOMING_FEEDRATE_Z  (4*60)
#define VALIDATE_HOMING_ENDSTOPS
#define EEPROM_CHITCHAT       // Give feedback on EEPROM commands. Disable to save PROGMEM.
#define EEPROM_BOOT_SILENT    // Keep M503 quiet and only give errors during first load
#define HOST_KEEPALIVE_FEATURE        // Disable this if your host doesn't like keepalive messages
#define DEFAULT_KEEPALIVE_INTERVAL 2  // Number of seconds between "busy" messages. Set with M113.
#define BUSY_WHILE_HEATING            // Some hosts require "busy" messages even during heating
#define PREHEAT_1_LABEL       "PLA"
#define PREHEAT_1_TEMP_HOTEND 180
#define PREHEAT_1_TEMP_BED     70
#define PREHEAT_1_FAN_SPEED     0 // Value from 0 to 255
#define PREHEAT_2_LABEL       "ABS"
#define PREHEAT_2_TEMP_HOTEND 240
#define PREHEAT_2_TEMP_BED    110
#define PREHEAT_2_FAN_SPEED     0 // Value from 0 to 255
#define PRINTJOB_TIMER_AUTOSTART
#define LCD_LANGUAGE en
#define DISPLAY_CHARSET_HD44780 JAPANESE
#define LCD_INFO_SCREEN_STYLE 0
#define SOFT_PWM_SCALE 0
#define SERVO_DELAY { 300 }

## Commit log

2020-03-15 FTI BRSC X, Y, Z base configuration
    [Configuration.h]
2020-03-17 FTI Strap brsc: pictures of initial version
2020-03-17 FTI-Strap brsc: refactored initial revision: plexi glass bed, replace FTI plastic parts by aluminium parts
2020-03-18 brsc FTI-1.0.0 fix extruder direction
    [Configuration.h]
2020-03-21 brsc FTI-1.0.0 mk8 extruder configuration
    [Configuration.h]
2020-03-22 brsc FTI-1.0.0 optimize configuration
    [Configuration.h]
2020-03-23 brsc FTI-1.0.0 configuration workaround: print with 0,4mm and half feed rate (in order to avoid printing 0,4mm height instead of 0,2mm defined by setup)
    [Configuration.h]
2020-03-24 brsc FTI-1.0.0 calibrate
    [Configuration.h]
2020-03-24 brsc FTI-1.0.0 half extrusion amount
    [Configuration.h]
2020-04-13 brsc FTI-1.1.0 print dimensions of refactored printer construction
    [Configuration.h]
2020-04-13 brsc FTI-1.1.0 initial calibration
    [Configuration.h]
2020-04-15 brsc FTI-1.1.0 increase y dimension
    [Configuration.h]
2020-04-21 brsc FTI-1.2.0 Fischertechnik adapter for aluminium square tube (in order to build a more stable chassis)
    [aluminum-square-tube-15x15-adapter-15.scad, aluminum-square-tube-15x15-adapter-15.stl, aluminum-square-tube-15x15-adapter-30.scad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]
2020-04-21 brsc FTI-1.2.0 rename custom part files
    [aluminum-square-tube-15x15-to-Fischertechnik-adapter-15.scad, aluminum-square-tube-15x15-to-Fischertechnik-adapter-15.stl, aluminum-square-tube-15x15-to-Fische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]
2020-04-21 brsc FTI-1.2.0 bugfixes in square tube to Fischertechnik adapter
    [aluminum-square-tube-15x15-to-Fischertechnik-adapter-15.scad, aluminum-square-tube-15x15-to-Fischertechnik-adapter-15.stl, aluminum-square-tube-15x15-to-Fische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]
2020-04-21 brsc FTI-1.2.0 bugfix: inner square tube diameter is 13
    [aluminum-square-tube-15x15-to-Fischertechnik-adapter-15.scad, aluminum-square-tube-15x15-to-Fischertechnik-adapter-15.stl, aluminum-square-tube-15x15-to-Fische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]
2020-04-21 brsc FTI-1.2.0 building block with hole (used for more stable Y-axis belt gear)
    [Fischertechnik-compatible-building-block-with-hole-90.scad, Fischertechnik-compatible-building-block-with-hole-90.stl]
2020-04-22 brsc FTI-1.2.0 fix custom part dimensions (adapt to current printer build)
    [Fischertechnik-compatible-building-block-with-hole-90.scad, Fischertechnik-compatible-building-block-with-hole-90.stl, aluminum-square-tube-15x15-to-Fischertec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]
2020-04-22 brsc FTI-1.2.0 custom part for Y-axis gear
    [Fischertechnik-compatible-building-block-with-hole-105.scad, Fischertechnik-compatible-building-block-with-hole-105.stl]
2020-04-23 brsc FTI-1.2.0 modify custom part: fix dimensions for printer, more generic with two holes
    [Fischertechnik-compatible-building-block-with-hole-105.scad, Fischertechnik-compatible-building-block-with-hole-105.stl, Fischertechnik-compatible-building-blo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]
2020-04-23 brsc FTI-1.2.0 fix custom part dimensions for this printer
    [aluminum-square-tube-15x15-to-Fischertechnik-adapter-15.scad, aluminum-square-tube-15x15-to-Fischertechnik-adapter-15.stl, aluminum-square-tube-15x15-to-Fische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]
2020-04-24 brsc FTI-1.2.0 fix square tube inner diameter
    [aluminum-square-tube-15x15-to-Fischertechnik-adapter-15.scad, aluminum-square-tube-15x15-to-Fischertechnik-adapter-15.stl, aluminum-square-tube-15x15-to-Fische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]
2020-04-25 brsc FTI-1.2.0 custom parts; X-Y-Z square tube connectors for base chassis
    [aluminum-square-tube-15x15-to-Fischertechnik-adapter-x-y-z-15-L.scad, aluminum-square-tube-15x15-to-Fischertechnik-adapter-x-y-z-15-L.stl, aluminum-square-tube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]
2020-04-25 brsc FTI-1.2.0 fix custom part dimensions
    [aluminum-square-tube-15x15-to-Fischertechnik-adapter-15.scad, aluminum-square-tube-15x15-to-Fischertechnik-adapter-15.stl, aluminum-square-tube-15x15-to-Fische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]
2020-04-25 brsc FTI-1.2.0 custom parts documentation
    [aluminum-square-tube-15x15-to-Fischertechnik-adapter-y-z-15.scad, aluminum-square-tube-15x15-to-Fischertechnik-adapter-y-z-15.stl]
2020-05-03 brsc FTI-1.2.0 optimize X- and Y-axis mechanics
    [Configuration.h]
2020-05-03 brsc FTI-1.2.0 increase X- and Y-axis feed rate
    [Configuration.h]
2020-05-04 brsc FTI-1.2.0 pictures, moved unused part CAD model into separate folder
    [Fischertechnik-compatible-building-block-with-hole-90.scad, Fischertechnik-compatible-building-block-with-hole-90.stl]
2020-05-04 brsc FTI-1.2.0 fix dimensions of custom parts, refactoring
    [aluminum-square-tube-15x15-to-Fischertechnik-adapter-15.scad, aluminum-square-tube-15x15-to-Fischertechnik-adapter-15.stl, aluminum-square-tube-15x15-to-Fische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]
2020-05-04 brsc FTI-1.2.1 custom parts
    [aluminum-square-tube-15x15-to-Fischertechnik-adapter-y-z-15-with-hole.scad, aluminum-square-tube-15x15-to-Fischertechnik-adapter-y-z-15-with-hole.stl]
2020-05-05 brsc FTI-1.2.1 custom part
    [aluminum-square-tube-15x15-to-Fischertechnik-adapter-x-y-15-X.scad, aluminum-square-tube-15x15-to-Fischertechnik-adapter-x-y-15-X.stl]
2020-05-05 brsc FTI-1.2.1 custom part, documentation
    [aluminum-square-tube-15x15-to-Fischertechnik-adapter-30.scad, aluminum-square-tube-15x15-to-Fischertechnik-adapter-30.stl]
2020-05-07 brsc FTI-1.2.1 Y-home position (endstop) is now in the front in order to fix mirrored printing
    [Configuration.h]
2020-05-07 brsc FTI-1.2.1 belt tensioner for X- and Y-axis, chassis refactoring
    [Belt_Tensioner.3dm, Belt_Tensioner.stl, Belt_Tensioner_-_Thicker.3dm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]
2020-05-07 brsc FTI-1.2.1 increase X- and Y-feedrate
    [Configuration.h]
2020-05-08 brsc FTI-1.2.1 fix chassis
    [aluminum-square-tube-15x15-to-Fischertechnik-adapter-45.scad, aluminum-square-tube-15x15-to-Fischertechnik-adapter-45.stl]
2020-05-08 brsc FTI-1.2.1 connector part
    [fischertechnik_double_groovepin_smartlab.stl]
2020-05-12 brsc FTI-1.2.1 custom parts for Z-axis elevation
2020-05-13 brsc FTI-1.2.1 custom axis adapter for GT2 pulleys on Fischertechnik axis
    [axis-5mm-to-4mm-Fischertechnik-adapter.scad, axis-5mm-to-4mm-Fischertechnik-adapter.stl]
2020-05-15 brsc FTI-1.2.1 unused parts
    [axis-5mm-to-4mm-Fischertechnik-adapter.scad, axis-5mm-to-4mm-Fischertechnik-adapter.stl]
2020-05-15 brsc FTI-1.2.1 optimized Z-axis drive
2020-05-19 brsc FTI-1.2.1 optimize Y-axis gear
2020-05-20 brsc FTI-1.2.1 optimized extruder mounting
2020-05-20 brsc FTI-1.2.1 update documentation
    [Configuration.h]
2020-05-27 brsc FTI-1.2.2 custom parts for print bed refactoring
    [aluminum-square-tube-15x15-to-Fischertechnik-adapter-30-DE.scad, aluminum-square-tube-15x15-to-Fischertechnik-adapter-30-DE.stl]
2020-05-27 brsc FTI-1.2.2 custom parts for print bed
    [aluminum-square-tube-15x15-to-Fischertechnik-adapter-75.scad, aluminum-square-tube-15x15-to-Fischertechnik-adapter-75.stl, aluminum-square-tube-15x15-to-Fische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]
2020-05-27 brsc FTI-1.2.2 fix dimensions of custom part in order to print it with the current printer build
    [aluminum-square-tube-15x15-to-Fischertechnik-adapter-75.scad, aluminum-square-tube-15x15-to-Fischertechnik-adapter-75.stl]
2020-06-08 brsc FTI-1.2.2 correct print dimensions
    [Configuration.h]
2020-06-12 brsc FTI-1.2.2 reduce extruder hotend temperature
    [Configuration.h]
2020-06-12 brsc FTI-1.2.2 set extruder maximum temperature to 230°C for MK8-Extruder
    [Configuration.h]
2020-06-20 brsc FTI-2.0.0 recalibrate X- and Y-axis
    [Configuration.h]

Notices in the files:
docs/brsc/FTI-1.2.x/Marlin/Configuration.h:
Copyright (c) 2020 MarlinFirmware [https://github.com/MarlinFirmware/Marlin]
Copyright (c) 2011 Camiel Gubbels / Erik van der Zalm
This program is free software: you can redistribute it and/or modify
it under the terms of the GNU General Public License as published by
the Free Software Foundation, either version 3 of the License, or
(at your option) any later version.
